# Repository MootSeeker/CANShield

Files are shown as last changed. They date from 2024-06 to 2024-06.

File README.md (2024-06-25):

# CANShield

STM32 Nucleo-64 Development Shield to connect NXP TJA1443 CANbus chip with some memory and GPS probe interface.

## Table of Contents
- [About](#about)
- [Features](#features)
- [Circuit Description](#circuit-description)
- [Hardware Requirements](#hardware-requirements)
- [Installation](#installation)
- [Usage](#usage)
- [Contributing](#contributing)
- [License](#license)
- [Contact](#contact)

## About
CANShield is a development shield designed for the STM32 Nucleo-64 board. It integrates an NXP TJA1443 CANbus transceiver, additional memory, and a GPS probe interface to facilitate the development and testing of CANbus applications. This shield provides a versatile and powerful platform for engineers and developers working on CANbus networks and applications, offering the tools needed to prototype and experiment with CAN-FD protocols.

## Features
- **Compatibility**: Fully compatible with STM32 Nucleo-64 boards, providing a seamless integration experience.
- **NXP TJA1443 CANbus Transceiver**: High-speed CAN-FD transceiver for robust and reliable CANbus communication.
- **Integrated Memory**: Additional memory for data storage, enabling complex applications and logging capabilities.
- **GPS Probe Interface**: Easy integration with GPS modules for applications requiring location data.
- **KiCad Design Files**: Open-source design files available, allowing for easy modifications and customizations.

## Circuit Description
This project includes the development and implementation of a custom development board with the NXP TJA1443 CAN-FD chip. The board connects to an Nucleo-64 development board, specifically the Nucleo-32G0B1, to fully exploit the capabilities of the CAN-FD interface.

The main purpose of this project is to utilize the full potential of the NXP TJA1443 chip in a CAN-FD network. By integrating this chip with the Nucleo-32G0B1, we aim to develop and test various protocols within the CAN network, providing a robust platform for CAN-FD communication.

Key Features:
- **NXP TJA1443 CAN-FD Chip**: High-speed CAN transceiver with advanced features for CAN-FD networks.
- **Nucleo-32G0B1 Compatibility**: Utilizes the STM32G0 microcontroller with integrated CAN-FD support.
- **Custom Development Board**: Tailored design for easy integration and testing of CAN-FD protocols.
- **Protocol Development and Testing**: Focus on creating and evaluating various protocols within the CAN network.

This project provides a comprehensive platform for developing and testing CAN-FD protocols, leveraging the capabilities of the NXP TJA1443 chip and the Nucleo-32G0B1 development board.

## Hardware Requirements
To get started with CANShield, you will need the following hardware components:
- **STM32 Nucleo-64 Board**: The main development board that hosts the STM32 microcontroller.
- **CANShield Board**: The custom shield that integrates the NXP TJA1443 CAN-FD transceiver, memory, and GPS interface.
- **GPS Probe (Optional)**: A GPS module for applications requiring geographic data.
- **Power Supply**: Appropriate power supply to power the Nucleo-64 and CANShield boards.

## Installation
1. **Clone the Repository**: Start by cloning the CANShield repository to your local machine.
    ```sh
    git clone https://github.com/MootSeeker/CANShield.git
    ```
2. **Open KiCad Project**: Open the KiCad project files located in the `CANShield` directory to review the schematics and PCB layout.
3. **Assemble the Shield**: Assemble the CANShield board according to the provided schematics and Bill of Materials (BOM). Ensure all components are correctly soldered and connected.
4. **Attach to Nucleo-64**: Connect the assembled CANShield board to the STM32 Nucleo-64 board.

## Usage
1. **Setup Hardware**: Attach the CANShield to the STM32 Nucleo-64 board. Connect the GPS probe to the shield if needed.
2. **Power Up**: Supply power to the setup using an appropriate power source.
3. **Program the STM32**: Upload your CANbus application code to the STM32 microcontroller using your preferred development environment (e.g., STM32CubeIDE).
4. **Monitor Communication**: Use CANbus monitoring tools to observe and debug the communication on the CANbus network. This can be done using software tools or hardware analyzers.

## Contributing
Contributions are welcome! Whether you have suggestions for improvements, bug fixes, or new features, please feel free to contribute. Here’s how you can get involved:
- **Open an Issue**: Report bugs or suggest features by opening an issue on the GitHub repository.
- **Submit a Pull Request**: Fork the repository, make your changes, and submit a pull request for review.
- **Documentation**: Help improve the project documentation by adding examples, tutorials, or clarifications.

## License
This project is licensed under the MIT License. You are free to use, modify, and distribute this project as per the terms of the license. See the [LICENSE](LICENSE) file for more details.

## Contact
For questions, feedback, or more information, please contact [MootSeeker](https://github.com/MootSeeker). We look forward to hearing from you and seeing how you use CANShield in your projects!

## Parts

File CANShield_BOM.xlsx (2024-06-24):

Comment | Designator | Footprint | JLCPCB Part # (optional)
10uF | C101,C109,C110 | Capacitor_SMD:C_0603_1608Metric_Pad1.08x0.95mm_HandSolder | C96446
100nF | C102,C107,C111,C113,C114 | Capacitor_SMD:C_0402_1005Metric_Pad0.74x0.62mm_HandSolder | C307331
47nF | C103,C105 | Capacitor_SMD:C_0402_1005Metric_Pad0.74x0.62mm_HandSolder | C1622
4700pF | C104 | Capacitor_SMD:C_0402_1005Metric_Pad0.74x0.62mm_HandSolder | C1538
10pF | C106,C108 | Capacitor_SMD:C_0402_1005Metric_Pad0.74x0.62mm_HandSolder | C32949
120uF | C112 | Capacitor_SMD:C_0603_1608Metric_Pad1.08x0.95mm_HandSolder | C2835554
PESD2CANFD27V-TR | CR101,CR102 | PESD2CANFD27V-TR:SOT23_PESD2_NEX | C552488
LED | D101 | LED_SMD:LED_0402_1005Metric_Pad0.77x0.64mm_HandSolder | C2856703
CDBU40-HF | D102 | Diode_SMD:D_0603_1608Metric | C3012735
LED_ARGB | D103,D104 | 155124M173200:LED_155124M173200
BLM15AG121SN1D | L101,L102,L103,L104,L105,L106,L107 | Inductor_SMD:L_0402_1005Metric_Pad0.77x0.64mm_HandSolder | C85812
Si1308EDL | Q101,Q102,Q103 | Package_TO_SOT_SMD:SOT-323_SC-70 | C469327
10k | R101, R102 | Resistor_SMD:R_0402_1005Metric_Pad0.72x0.64mm_HandSolder | C25744
0E | R103,R105,R118,R119,R124,R125,R126 | Resistor_SMD:R_0402_1005Metric_Pad0.72x0.64mm_HandSolder | C472872
60E | R104, R106 | Resistor_SMD:R_0603_1608Metric_Pad0.98x0.95mm_HandSolder | C911580
1k | R107,R110,R116,R123 | Resistor_SMD:R_0402_1005Metric_Pad0.72x0.64mm_HandSolder | C2763771
100k | R108,R109,R111,R112,R113,R114,R115,R117,R120,R121. R122 | Resistor_SMD:R_0402_1005Metric_Pad0.72x0.64mm_HandSolder | C427222
TJA1443ATK/0Z | U101 | TJA1443ATK:HVSON14_SOT1086-2_NXP | C5202327
BD2222G | U102 | Package_SO:TSOP-6_1.65x3.05mm_P0.95mm | C559606
AT25SF081-XMHD-X | U103 | Package_SO:TSSOP-8_4.4x3mm_P0.65mm | C2061730
MR20H40 | U104 | Package_SO:SOIC-8-1EP_3.9x4.9mm_P1.27mm_EP2.29x3mm | C19308182

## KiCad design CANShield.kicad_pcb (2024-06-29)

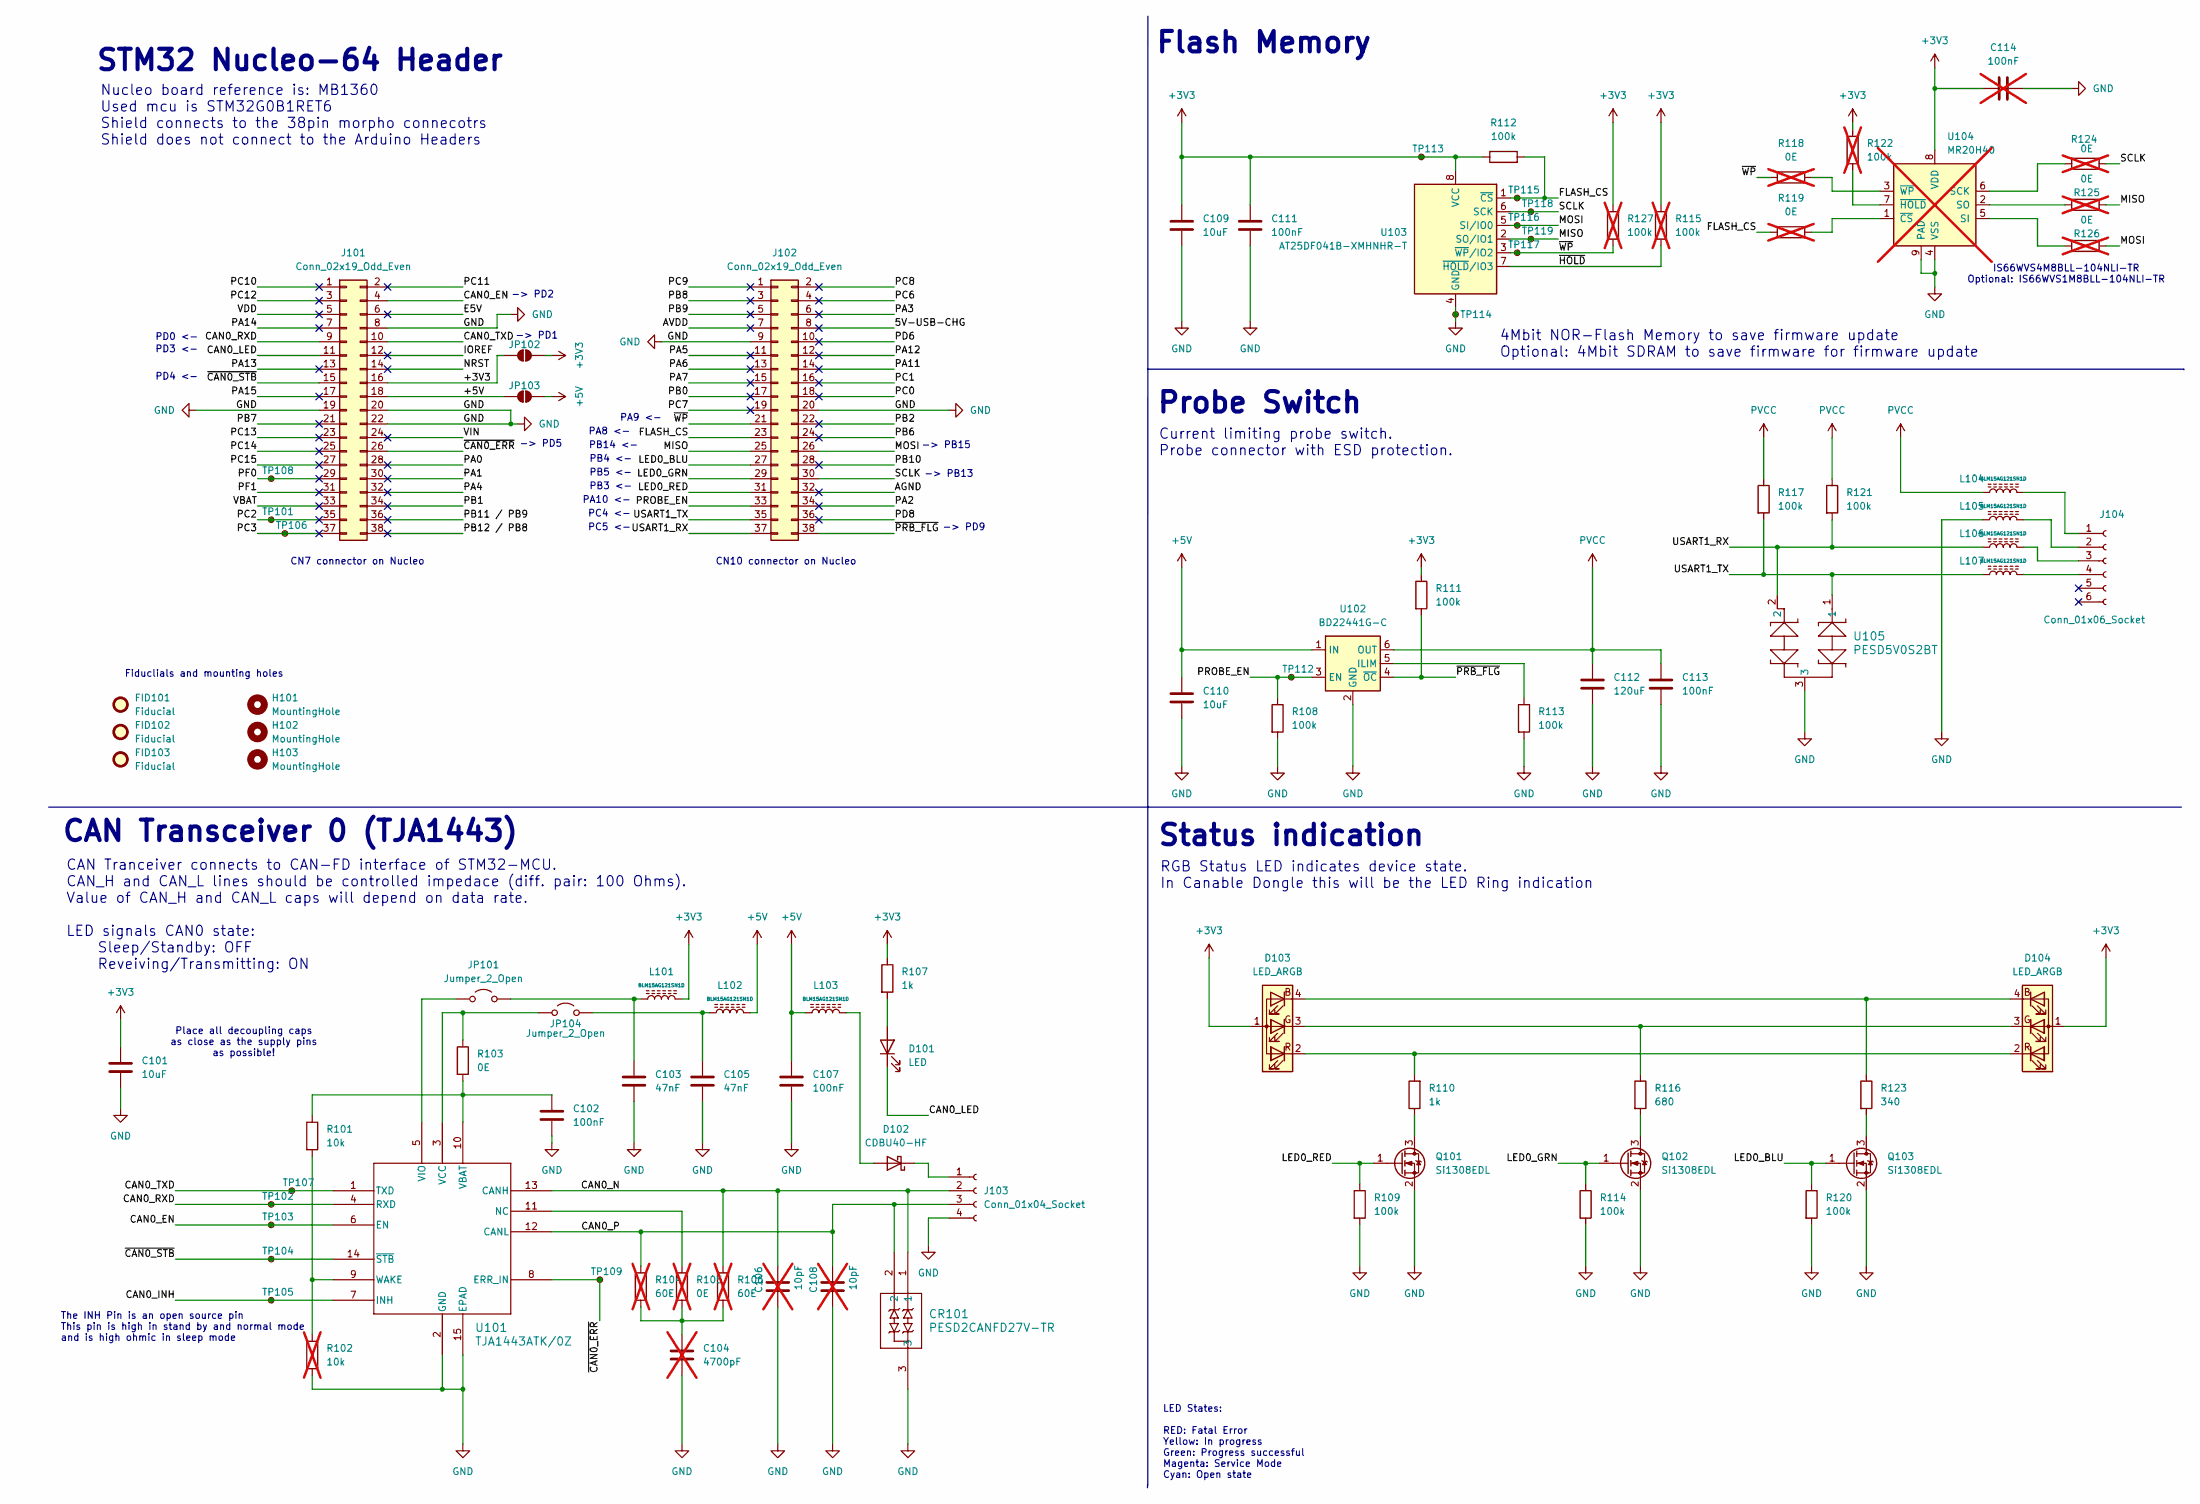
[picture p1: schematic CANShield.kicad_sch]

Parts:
C101, C109, C110: 10uF; C_0603_1608Metric_Pad1.08x0.95mm_HandSolder; JLCPCB Part # (optional) ${ITEM_NUMBER}
C102, C107, C111, C113: 100nF; C_0402_1005Metric_Pad0.74x0.62mm_HandSolder; JLCPCB Part # (optional) ${ITEM_NUMBER}
C103, C105: 47nF; C_0402_1005Metric_Pad0.74x0.62mm_HandSolder; JLCPCB Part # (optional) ${ITEM_NUMBER}
C104: 4700pF; C_0402_1005Metric_Pad0.74x0.62mm_HandSolder; JLCPCB Part # (optional) ${ITEM_NUMBER}; not fitted
C106, C108: 10pF; C_0402_1005Metric_Pad0.74x0.62mm_HandSolder; JLCPCB Part # (optional) ${ITEM_NUMBER}; not fitted
C112: 120uF; C_0603_1608Metric_Pad1.08x0.95mm_HandSolder; JLCPCB Part # (optional) ${ITEM_NUMBER}
C114: 100nF; C_0402_1005Metric_Pad0.74x0.62mm_HandSolder; JLCPCB Part # (optional) ${ITEM_NUMBER}; not fitted
CR101: PESD2CANFD27V-TR; SOT23_PESD2_NEX; JLCPCB Part # (optional) ${ITEM_NUMBER}
D101: LED; LED_0402_1005Metric_Pad0.77x0.64mm_HandSolder; JLCPCB Part # (optional) ${ITEM_NUMBER}
D102: CDBU40-HF; D_0603_1608Metric; JLCPCB Part # (optional) ${ITEM_NUMBER}
D103, D104: LED_ARGB; LED_155124M173200; JLCPCB Part # (optional) ${ITEM_NUMBER}
FID101, FID102, FID103: Fiducial; Fiducial_0.75mm_Mask2.25mm; JLCPCB Part # (optional) ${ITEM_NUMBER}
H101, H102, H103: MountingHole; MountingHole_2.7mm_M2.5; JLCPCB Part # (optional) ${ITEM_NUMBER}
J101, J102: Conn_02x19_Odd_Even; PinSocket_2x19_P2.54mm_Vertical; JLCPCB Part # (optional) ${ITEM_NUMBER}
J103: Conn_01x04_Socket; PinHeader_1x04_P2.54mm_Horizontal; JLCPCB Part # (optional) ${ITEM_NUMBER}
J104: Conn_01x06_Socket; Molex_PicoBlade_53048-0610_1x06_P1.25mm_Horizontal; JLCPCB Part # (optional) ${ITEM_NUMBER}
JP101, JP104: Jumper_2_Open; PinHeader_1x02_P2.54mm_Vertical; JLCPCB Part # (optional) ${ITEM_NUMBER}
JP102, JP103: SolderJumper_2_Open; PinHeader_1x02_P2.54mm_Vertical; JLCPCB Part # (optional) ${ITEM_NUMBER}
L101, L102, L103, L104, L105, L106, L107: BLM15AG121SN1D; L_0402_1005Metric_Pad0.77x0.64mm_HandSolder; JLCPCB Part # (optional) ${ITEM_NUMBER}
Q101, Q102, Q103: Si1308EDL; SOT-323_SC-70; JLCPCB Part # (optional) ${ITEM_NUMBER}
R101: 10k; R_0402_1005Metric_Pad0.72x0.64mm_HandSolder; JLCPCB Part # (optional) ${ITEM_NUMBER}
R102: 10k; R_0402_1005Metric_Pad0.72x0.64mm_HandSolder; JLCPCB Part # (optional) ${ITEM_NUMBER}; not fitted
R103: 0E; R_0402_1005Metric_Pad0.72x0.64mm_HandSolder; JLCPCB Part # (optional) ${ITEM_NUMBER}
R104, R106: 60E; R_0603_1608Metric_Pad0.98x0.95mm_HandSolder; JLCPCB Part # (optional) ${ITEM_NUMBER}; not fitted
R105: 0E; R_0603_1608Metric_Pad0.98x0.95mm_HandSolder; JLCPCB Part # (optional) ${ITEM_NUMBER}; not fitted
R107, R110: 1k; R_0402_1005Metric_Pad0.72x0.64mm_HandSolder; JLCPCB Part # (optional) ${ITEM_NUMBER}
R108, R109, R111, R112, R113, R114, R117, R120, R121: 100k; R_0402_1005Metric_Pad0.72x0.64mm_HandSolder; JLCPCB Part # (optional) ${ITEM_NUMBER}
R115, R122, R127: 100k; R_0402_1005Metric_Pad0.72x0.64mm_HandSolder; JLCPCB Part # (optional) ${ITEM_NUMBER}; not fitted
R116: 680; R_0402_1005Metric_Pad0.72x0.64mm_HandSolder; JLCPCB Part # (optional) ${ITEM_NUMBER}
R118, R119, R124, R125, R126: 0E; R_0402_1005Metric_Pad0.72x0.64mm_HandSolder; JLCPCB Part # (optional) ${ITEM_NUMBER}; not fitted
R123: 340; R_0402_1005Metric_Pad0.72x0.64mm_HandSolder; JLCPCB Part # (optional) ${ITEM_NUMBER}
TP101, TP102, TP103, TP104, TP105, TP106, TP107, TP108, TP109, TP112, TP113, TP114, TP115, TP116, TP117, TP118, TP119: TestPoint_Small; TestPoint_Pad_D1.0mm; JLCPCB Part # (optional) ${ITEM_NUMBER}
U101: TJA1443ATK/0Z; HVSON14_SOT1086-2_NXP; JLCPCB Part # (optional) ${ITEM_NUMBER}
U102: BD22441G-C; TSOP-6_1.65x3.05mm_P0.95mm; JLCPCB Part # (optional) C5576416
U103: AT25DF041B-XMHNHR-T; TSSOP-8_4.4x3mm_P0.65mm; JLCPCB Part # (optional) ${ITEM_NUMBER}
U104: MR20H40; SOIC-8-1EP_3.9x4.9mm_P1.27mm_EP2.29x3mm; JLCPCB Part # (optional) ${ITEM_NUMBER}; not fitted
U105: PESD5V0S2BT; SOT23_NEX

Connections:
+3V3: C101.1, C109.1, C111.1, C114.1, D103.1 (A), D104.1 (A), J101.16, JP102.1 (A), JP102.2 (B), L101.2, R107.1, R111.1, R112.1, R115.1, R122.2, R127.1, TP113.1, U103.8 (VCC), U104.8 (VDD)
+5V: C107.1, C110.1, J101.18, JP103.1 (A), JP103.2 (B), L102.2, L103.1, U102.1 (IN)
/5V-USB-CHG: J102.8
/AGND: J102.32
/AVDD: J102.7
/CAN0_EN: J101.4, TP103.1, U101.6 (EN)
/CAN0_INH: TP105.1, U101.7 (INH)
/CAN0_LED: D101.1 (K), J101.11
/CAN0_N: C106.1, CR101.1, J103.2, R106.1, U101.13 (CANH)
/CAN0_P: C108.1, CR101.2, J103.3, R104.1, U101.12 (CANL)
/CAN0_RXD: J101.9, TP102.1, U101.4 (RXD)
/CAN0_TXD: J101.10, TP107.1, U101.1 (TXD)
/E5V: J101.6
/FLASH_CS: J102.23, R112.2, R119.1, TP115.1, U103.1 (~CS)
/IOREF: J101.12
/LED0_BLU: J102.27, Q103.1 (G), R120.1
/LED0_GRN: J102.29, Q102.1 (G), R114.1
/LED0_RED: J102.31, Q101.1 (G), R109.1
/MISO: J102.25, R125.1, TP119.1, U103.2 (SO/IO1)
/MOSI: J102.26, R126.1, TP116.1, U103.5 (SI/IO0)
/NRST: J101.14
/PA0: J101.28
/PA1: J101.30
/PA2: J102.34
/PA3: J102.6
/PA4: J101.32
/PA5: J102.11
/PA6: J102.13
/PA7: J102.15
/PA11: J102.14
/PA12: J102.12
/PA13: J101.13
/PA14: J101.7
/PA15: J101.17
/PB0: J102.17
/PB1: J101.34
/PB2: J102.22
/PB6: J102.24
/PB7: J101.21
/PB8: J102.3
/PB9: J102.5
/PB10: J102.28
/PB11 / PB9: J101.36
/PB12 / PB8: J101.38
/PC0: J102.18
/PC1: J102.16
/PC2: J101.35, TP101.1
/PC3: J101.37, TP106.1
/PC6: J102.4
/PC7: J102.19
/PC8: J102.2
/PC9: J102.1
/PC10: J101.1
/PC11: J101.2
/PC12: J101.3
/PC13: J101.23
/PC14: J101.25
/PC15: J101.27
/PD6: J102.10
/PD8: J102.36
/PF0: J101.29, TP108.1
/PF1: J101.31
/PROBE_EN: J102.33, R108.1, TP112.1, U102.3 (EN)
/SCLK: J102.30, R124.1, TP118.1, U103.6 (SCK)
/USART1_RX: J102.37, L106.1, R121.2, U105.2
/USART1_TX: J102.35, L107.1, R117.2, U105.1
/VBAT: J101.33
/VDD: J101.5
/VIN: J101.24
/~CAN0_ERR: J101.26, TP109.1, U101.8 (ERR_IN)
/~CAN0_STB: J101.15, TP104.1, U101.14 (~STB)
/~HOLD: R115.2, U103.7 (~HOLD/IO3)
/~PRB_FLG: J102.38, R111.2, U102.4 (~OC)
/~WP: J102.21, R118.1, R127.2, TP117.1, U103.3 (~WP/IO2)
GND: C101.2, C102.2, C103.2, C104.2, C105.2, C106.2, C107.2, C108.2, C109.2, C110.2, C111.2, C112.2, C113.2, C114.2, CR101.3, J101.8, J101.19, J101.20, J101.22, J102.9, J102.20, J103.4, L105.1, Q101.2 (S), Q102.2 (S), Q103.2 (S), R102.2, R108.2, R109.2, R113.2, R114.2, R120.2, TP114.1, U101.2 (GND), U101.15 (EPAD), U102.2 (GND), U103.4 (GND), U104.4 (VSS), U104.9 (PAD), U105.3
unnamed: C104.1, R104.2, R105.1, R106.2
unnamed: D101.2 (A), R107.2
unnamed: D102.2 (A), L103.2
unnamed: D102.1 (K), J103.1
unnamed: D103.4 (BK), D104.4 (BK), R123.1
unnamed: D103.3 (GK), D104.3 (GK), R116.1
unnamed: D103.2 (RK), D104.2 (RK), R110.2
unnamed: J104.1, L104.2
unnamed: J104.2, L105.2
unnamed: J104.3, L106.2
unnamed: J104.4, L107.2
unnamed: JP101.1 (A), U101.5 (VIO)
unnamed: C103.1, JP101.2 (B), L101.1
unnamed: JP104.1 (A), R103.1, U101.3 (VCC)
unnamed: C105.1, JP104.2 (B), L102.1
unnamed: Q101.3 (D), R110.1
unnamed: Q102.3 (D), R116.2
unnamed: Q103.3 (D), R123.2
unnamed: R105.2, U101.11 (NC)
unnamed: C102.1, R101.1, R103.2, U101.10 (VBAT)
unnamed: R101.2, R102.1, U101.9 (WAKE)
unnamed: R113.1, U102.5 (ILIM)
unnamed: R124.2, U104.6 (SCK)
unnamed: R126.2, U104.5 (SI)
unnamed: R125.2, U104.2 (SO)
unnamed: R119.2, U104.1 (~CS)
unnamed: R122.1, U104.7 (~HOLD)
unnamed: R118.2, U104.3 (~WP)
PVCC: C112.1, C113.1, L104.1, R117.1, R121.1, U102.6 (OUT)

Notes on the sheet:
CAN Transceiver 0 (TJA1443)
CN7 connector on Nucleo
PD4 <-
RGB Status LED indicates device state. In Canable Dongle this will be the LED Ring indication
-> PD1
PB5 <-
PA9 <-
PB4 <-
The INH Pin is an open source pin This pin is high in stand by and normal mode and is high ohmic in sleep mode
IS66WVS4M8BLL-104NLI-TR Optional: IS66WVS1M8BLL-104NLI-TR
PC5 <-
STM32 Nucleo-64 Header
Nucleo board reference is: MB1360 Used mcu is STM32G0B1RET6 Shield connects to the 38pin morpho connecotrs Shield does not connect to the Arduino Headers
Place all decoupling caps as close as the supply pins as possible!
Status indication
PB3 <-
Probe Switch
CN10 connector on Nucleo
PA8 <-
-> PB15
CAN Tranceiver connects to CAN-FD interface of STM32-MCU. CAN_H and CAN_L lines should be controlled impedace (diff. pair: 100 Ohms). Value of CAN_H and CAN_L caps will depend on data rate. LED signals CAN0 state: Sleep/Standby: OFF Reveiving/Transmitting: ON
-> PD9
-> PD5
4Mbit NOR-Flash Memory to save firmware update Optional: 4Mbit SDRAM to save firmware for firmware update
Current limiting probe switch. Probe connector with ESD protection.
PD0 <-
PB14 <-
-> PB13
PC4 <-
Flash Memory
LED States: RED: Fatal Error Yellow: In progress Green: Progress successful Magenta: Service Mode Cyan: Open state
Fiduclials and mounting holes
-> PD2
PD3 <-
PA10 <-

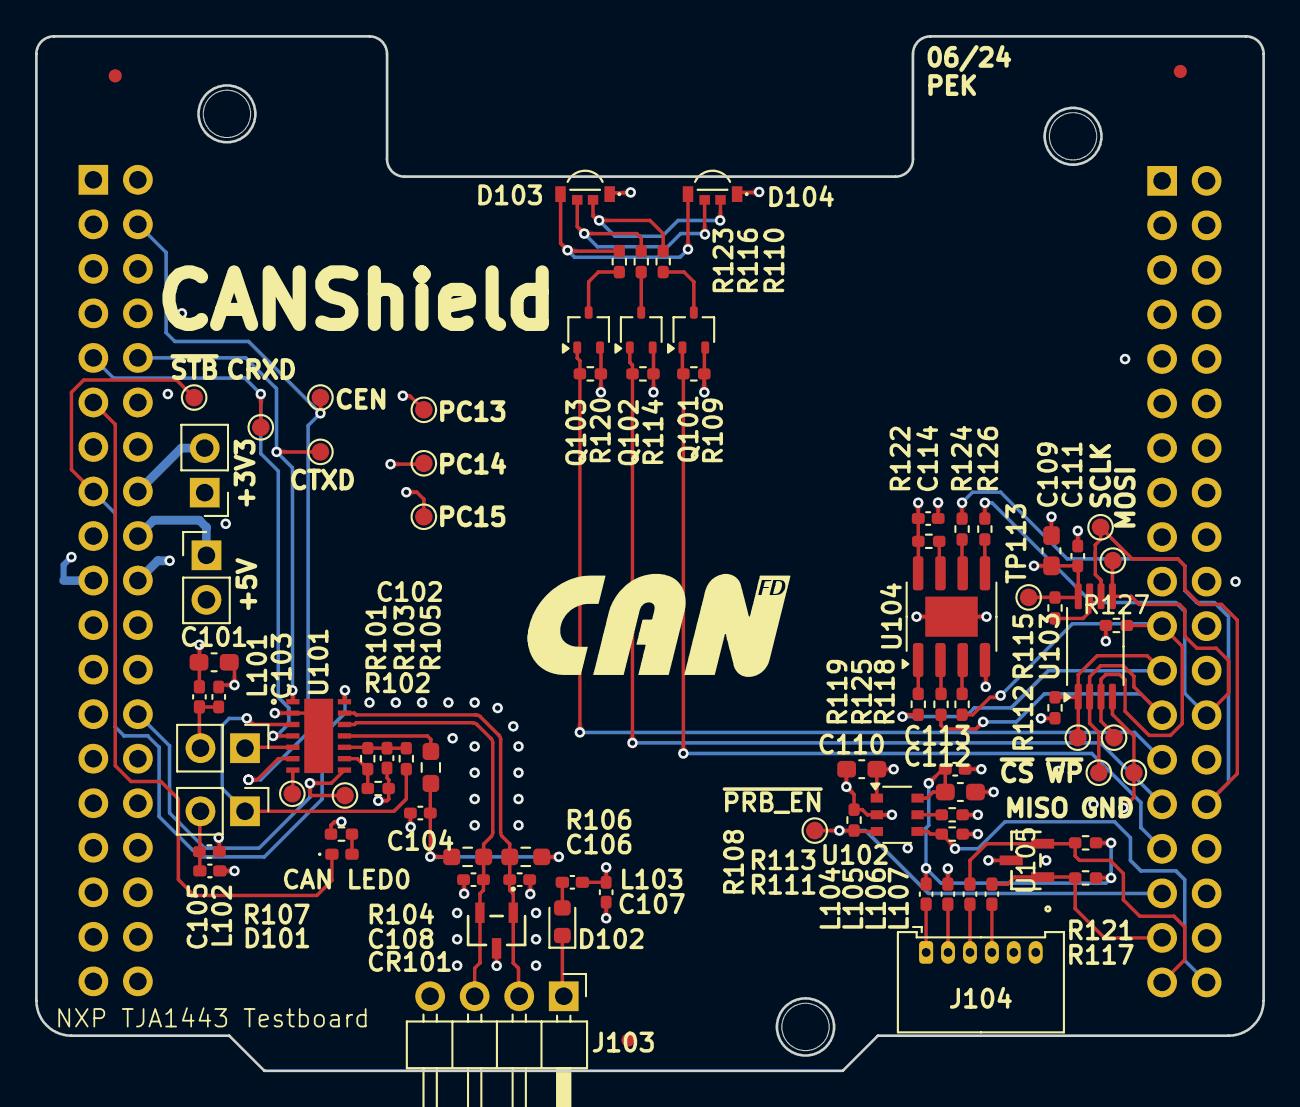
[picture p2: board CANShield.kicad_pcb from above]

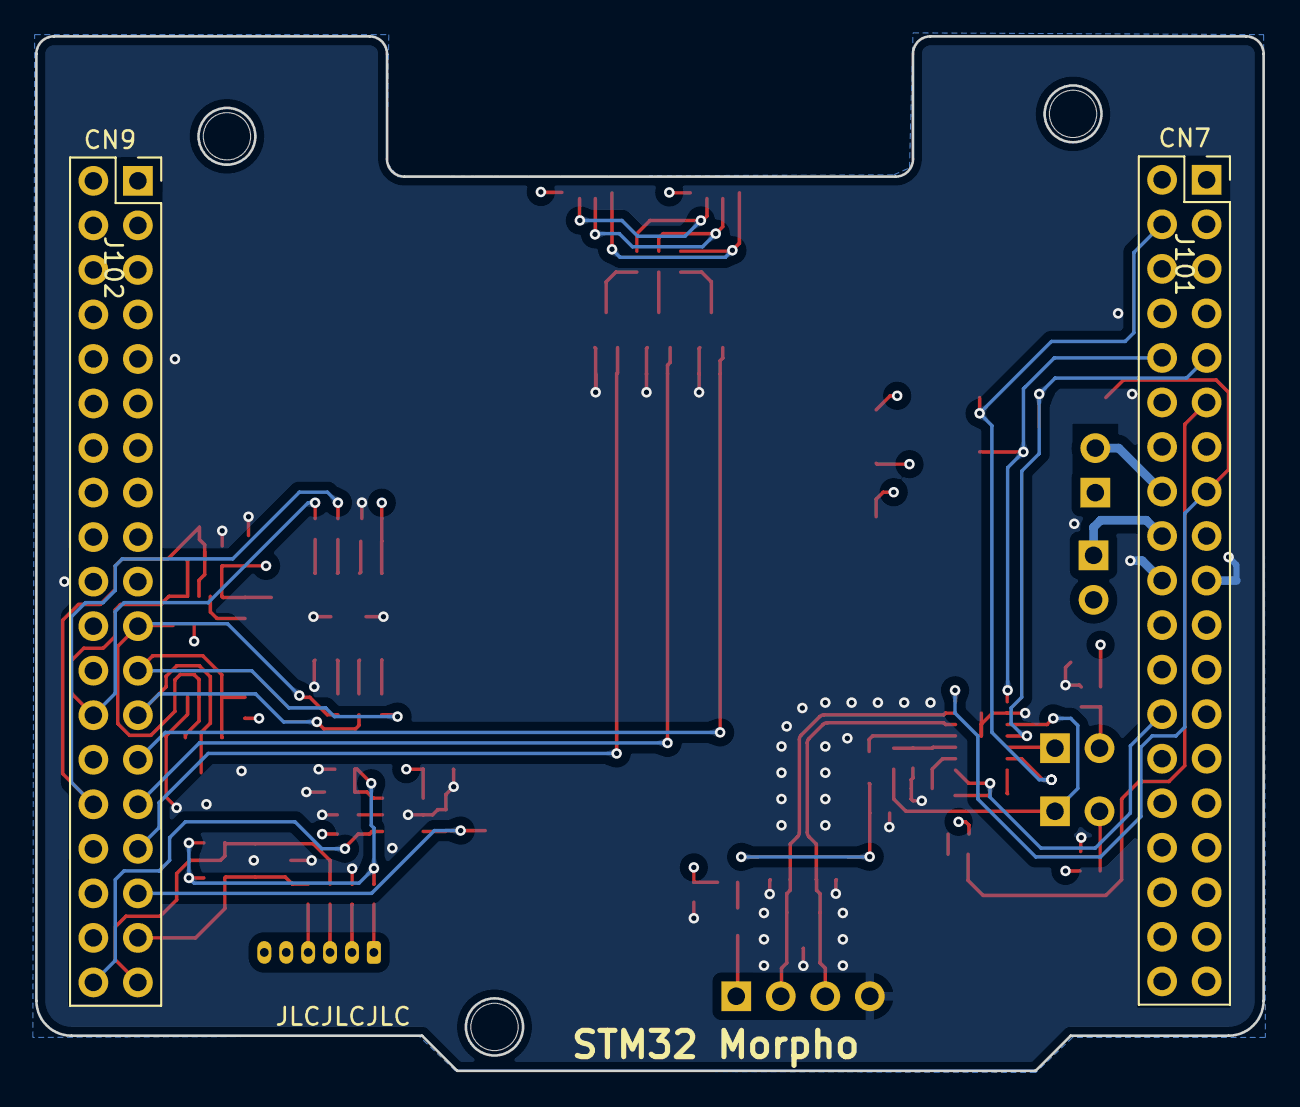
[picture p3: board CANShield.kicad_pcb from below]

Board: 4 copper layers, 70.0 x 59.0 mm, 91 parts (2 on the bottom side), 57 nets.

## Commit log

2024-06-19 Add project
    [CANShield.kicad_pcb, CANShield.kicad_sch]
2024-06-19 Moved files one folder up
    [CANShield.kicad_pcb, CANShield.kicad_sch]
2024-06-19 Save schematics
    [CANShield.kicad_sch]
2024-06-20 Add NXP TJA1443 CAN-FD Chip
    Add reference design for CAN-FD chip
    [CANShield.kicad_sch]
2024-06-20 Update CANShield.kicad_sch
    Add complete Nucleo Pinout
    [CANShield.kicad_sch]
2024-06-20 Update CANShield.kicad_sch
    Add testpoints and documentation
    [CANShield.kicad_sch]
2024-06-21 Update CANShield.kicad_sch
    Add probe connector and Flash memory
    [CANShield.kicad_sch]
2024-06-22 Add PCB
    started design
    [CANShield.kicad_pcb, CANShield.kicad_sch]
2024-06-23 pcb in progress
    working on pcb layout
    [CANShield.kicad_pcb, CANShield.kicad_sch]
2024-06-23 working on PCB
    [CANShield.kicad_pcb, CANShield.kicad_sch]
2024-06-24 finished PCB
    [CANShield.kicad_pcb]
2024-06-24 Add BOM to project
    Add BOM and did Gerber Data
    [CANShield.kicad_pcb, CANShield.kicad_sch, CANShield_BOM.xlsx]
2024-06-24 update BOM
    [CANShield_BOM.xlsx]
2024-06-25 Update BOM
    Small changes on pcb layout and update BOM
    [CANShield.kicad_pcb, CANShield.kicad_sch]
2024-06-27 Add bew esd diode
    [CANShield.kicad_pcb, CANShield.kicad_sch]
2024-06-27 Moved Testpoints
    [CANShield.kicad_pcb, CANShield.kicad_sch]
2024-06-29 changes from pcb review
    update pcb with remained changes in pcb review.
    [CANShield.kicad_pcb]
2024-06-29 Update CANShield.kicad_pcb
    all changes from review. PCB ready for final review.
    [CANShield.kicad_pcb]
